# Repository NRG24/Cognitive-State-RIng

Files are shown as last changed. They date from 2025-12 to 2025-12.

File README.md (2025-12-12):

This is a sensor packed device that features a GSR sensor and max30102 sensor that measure skin electrical conductivity (arousal), temperature, spo2, heart rate, and HRV. The point of this is to build a tracker that isn't focused on fitness, but cognitive health tied to the nervous system. These sensors will be packed into a small PCB that goes on one of the two rings. There is a ring on the index finger with the PCB+ one electrode and the other ring on the middle finger has the other electrode. This data is controlled by the nrf52840, a small MCU on the PCB, and sent via Bluetooth low energy to a mobile based Flutter app. The data goes through a filter, removing any outliers. Additionally, in the app there is a "Cognitive Score." The app interprets all the data and based off of an algorithm, it can give you a score out of 100 as well as some insights.

Bill of Materials:
https://docs.google.com/spreadsheets/d/1M4TGVIU_XtcH1ejhJ6mys-NpG31-dXWfCi7Ya9xVGhs/edit?usp=sharing

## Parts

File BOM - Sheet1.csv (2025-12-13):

Item | Description | Quantity | Unit Price | Total Price | URL | FINAL TOTAL | Notes
XIAO nRF52840 Sense | Breakout MCU | 1 | $25.99 | $25.99 | https://www.amazon.com/Seeed-Studio-XIAO-nRF52840Sense/dp/B09T94SZ8K?th=1 | 27.81 | Amazon ultimately has the best price for the XIAO
Grove GSR Sensor | Breakout GSR Sensor | 1 | 10.9 | 10.9 | https://www.digikey.com/en/products/detail/seeed-technology-co-ltd/101020052/5488086 | 20.31 | REVISED: Digikey has the best price for this gsr sensor
Max30102 | Heart rate sensor breakout | 1 | 6.99 | 6.99 | https://www.amazon.com/AEDIKO-MAX30102-Detection-Concentration-Compatible/dp/B09LQDW27N | 14.96 | I can't and wont switch this. Amazon here has the best price and also there are many counterfeits of these sensors but I know this exact one works well based off research.
Aypzuke 10cm+20cm 240pc | Jumper Cables | 1 | 1.95 | 1.95 | https://www.digikey.com/en/products/detail/adafruit-industries-llc/1954/6827087?gclsrc=aw.ds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 | 9.57 | Reduced price by 10 by switching to digikey
Remote Finger Sensor For | Electrodes | 1 | 32.4 | 32.4 | https://bio-medical.com/remote-finger-sensor-for-gsr2.html | 44.9 | Best price here and it has the proper dimensions
USB_C_Receptacle_USB2.0_16P | USBC Port J1 | 2 | 0.78 | 1.56 | https://www.digikey.com/en/products/detail/gct/USB4105-GF-A-060/14559043?gclsrc=aw.ds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 | 10.73 | From here down I got the best price or only price possible
4.7uf Capacitor | Cap C6 | 2 | 0.12 | 0.24 | https://www.mouser.com/ProductDetail/TAIYO-YUDEN/LMK212BJ475KG-T | 8.93
0.1uF Capacitor | Cap C3, C_GSR1 | 4 | 0.11 | 0.44 | https://www.mouser.com/ProductDetail/581-06036C104JAT2A | 9.06
AKZYTUE 3.7V 40mAh 301020 Lipo Battery | Battery | 2 | 7.29 | 14.58 | https://www.amazon.com/AKZYTUE-Battery-Rechargeable-Lithium-Connector/dp/B07TWHGHW4?s=electronics | 23.08
MDBT50Q-P1MV2 | PCB MCU | 2 | 6 | 12 | https://www.digikey.com/en/products/detail/raytac/MDBT50Q-P1MV2/13677599?gclsrc=aw.ds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 | 34.24
KYOCERA AVX KAM15CT70J226MT | Cap c1 and c2 | 2 | 0.46 | 0.92 | https://www.mouser.com/ProductDetail/KYOCERA-AVX/KAM15CT70J226MT?qs=Tc%252BHE9vUsnt72L0VWwenIA%3D%3D | 9.63
Samsung Electro-Mechanics CL03A105MQ3CSWC | MCU CAPS | 18 | 0.065 | 1.17 | https://www.mouser.com/ProductDetail/Samsung-Electro-Mechanics/CL03A105MQ3CSWC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 | 9.99
36-5019TR-ND | Test points | 4 | 0.37 | 1.48 | https://www.digikey.com/en/products/detail/keystone-electronics/5019/3907344?gclsrc=aw.ds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 | 9.3
Draloric TNPU06034K70AZEN00 | resistors r1,r2 | 4 | 2.21 | 8.84 | https://www.mouser.com/ProductDetail/71-TNPU06034K70AZEN0 | 18.01
Panasonic ERA-3APB303V | resistor r3 | 2 | 0.24 | 0.48 | https://www.mouser.com/ProductDetail/667-ERA-3APB303V | 9.06
Bourns CR0603-FX-5101ELF | Resistor r4,r5 | 4 | 0.1 | 0.4 | https://www.mouser.com/ProductDetail/652-CR0603FX-5101ELF | 8.98
Vishay / Beyschlag MCT06030C2203FP500 | R_GSR resistor | 2 | 0.1 | 0.2 | https://www.mouser.com/ProductDetail/594-MCT06030C2203FP5 |  | Cart combined w/ item below
Panasonic ERA-3AED104V | R_PROTECT | 2 | 0.1 | 0.2 | https://www.mouser.com/ProductDetail/667-ERA-3AED104V | 8.98
579-MCP1700T1802E/TT | LDO | 2 | 0.51 | 1.02 | https://www.mouser.com/ProductDetail/Microchip-Technology/MCP1700T-1802E-TT?qs=YUl711QUJY0TiDgzmNmFrg%3D%3D | 9.64
579-MCP73831T-2ACIOT | charger | 2 | 0.76 | 1.52 | https://www.mouser.com/ProductDetail/Microchip-Technology/MCP73831T-2ACI-OT?qs=yUQqVecv4qvbBQBGbHx0Mw%3D%3D | 10.18
PCB |  | 5 |  |  |  | 50.52
 |  |  |  |  | TOTAL: | 347.88

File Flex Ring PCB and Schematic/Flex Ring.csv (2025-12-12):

Id | Designator | Footprint | Quantity | Designation | Supplier and ref
1 | C10,C12,C5,C13,C11,C9,C8,C7,C4 | C_0603_1608Metric | 9 | 1uF
2 | U4 | Nordic_AQFN-73-1EP_7x7mm_P0.5mm | 1 | nRF52840
3 | BT1 | SolderWire-0.127sqmm_1x02_P3.7mm_D0.48mm_OD1mm | 1 | Battery
4 | C1,C2 | C_0603_1608Metric | 2 | 10uF
5 | J1 | USB_C_Receptacle_HRO_TYPE-C-31-M-12 | 1 | USB_C_Receptacle_USB2.0_16P
6 | U1 | SOT-23 | 1 | MCP1700x-180xxTT
7 | U2 | SOT-23-5 | 1 | MCP73831-2-OT
8 | E1 | TestPoint_Pad_D2.0mm | 1 | TestPoint
9 | E2 | SolderWire-0.1sqmm_1x01_D0.4mm_OD1mm | 1 | TestPoint
10 | C6 | C_0805_2012Metric | 1 | 4.7uF
11 | U5 | Maxim_OLGA-14_3.3x5.6mm_P0.8mm | 1 | MAX30102
12 | R3 | R_0603_1608Metric | 1 | 30k
13 | R_PROTECT1 | R_0603_1608Metric | 1 | 100k
14 | R_GSR1 | R_0603_1608Metric | 1 | 220k
15 | C_GSR1,C3 | C_0603_1608Metric | 2 | .1uF
16 | R5,R4 | R_0603_1608Metric | 2 | 5.1k
17 | R2,R1 | R_0603_1608Metric | 2 | 4.7k
18 | J2 | PinHeader_2x05_P1.27mm_Vertical | 1 | SWD_HEADER

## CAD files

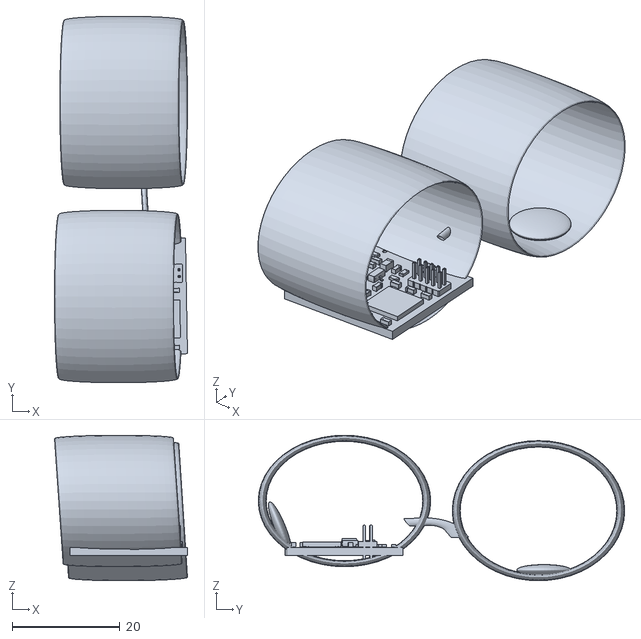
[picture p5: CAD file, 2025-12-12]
3D CAD MODEL.stl
24.7 x 68.0 x 27.0

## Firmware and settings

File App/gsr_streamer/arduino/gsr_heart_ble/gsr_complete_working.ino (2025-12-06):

#include <Wire.h>
#include "MAX30105.h"
#include "heartRate.h"
#include <ArduinoBLE.h>

MAX30105 particleSensor;

BLEService bioService("19B10000-E8F2-537E-4F6C-D104768A1214");
BLEIntCharacteristic gsrChar("19B10002-E8F2-537E-4F6C-D104768A1214", BLERead | BLENotify);
BLEIntCharacteristic heartChar("19B10003-E8F2-537E-4F6C-D104768A1214", BLERead | BLENotify);
BLEFloatCharacteristic tempChar("19B10004-E8F2-537E-4F6C-D104768A1214", BLERead | BLENotify);
BLEFloatCharacteristic hrvChar("19B10005-E8F2-537E-4F6C-D104768A1214", BLERead | BLENotify);
BLEIntCharacteristic spo2Char("19B10006-E8F2-537E-4F6C-D104768A1214", BLERead | BLENotify);

bool deviceConnected = false;

const byte RATE_SIZE = 20;
byte rates[RATE_SIZE];
byte rateSpot = 0;
long lastBeat = 0;
float beatsPerMinute = 0;
int beatAvg = 0;
float smoothedBPM = 0.0;

const int HRV_BUFFER_SIZE = 10;
unsigned long rrIntervals[HRV_BUFFER_SIZE];
int rrIndex = 0;
unsigned long lastRRTime = 0;
float hrv = 0.0;

const int GSR_PIN = A0;
float gsrValue = 0.0;
const int GSR_SAMPLES = 10;
float gsrReadings[GSR_SAMPLES] = {0};
int gsrIndex = 0;

float spo2 = 98.0;
float redACValue = 0, irACValue = 0;
float redDCValue = 0, irDCValue = 0;
int spo2SampleCount = 0;

float temperature = 0.0;
unsigned long lastTempRead = 0;
const unsigned long TEMP_READ_INTERVAL = 2000;

void setup() {
  Serial.begin(9600);
  delay(1000);
  Serial.println("=== GSR Streamer ===");
  
  Serial.print("Initializing MAX30102... ");
  if (!particleSensor.begin(Wire, I2C_SPEED_FAST)) {
    Serial.println("FAILED!");
    while (1);
  }
  Serial.println("OK");
  
  byte ledBrightness = 0x1F;
  byte sampleAverage = 4;
  byte ledMode = 2;
  int sampleRate = 400;
  int pulseWidth = 411;
  int adcRange = 4096;
  
  particleSensor.setup(ledBrightness, sampleAverage, ledMode, sampleRate, pulseWidth, adcRange);
  particleSensor.setPulseAmplitudeRed(0x1F);
  particleSensor.setPulseAmplitudeGreen(0);
  particleSensor.enableDIETEMPRDY();
  
  Serial.print("Initializing BLE... ");
  if (!BLE.begin()) {
    Serial.println("FAILED!");
    while (1);
  }
  Serial.println("OK");
  
  BLE.setLocalName("GSR_HEART");
  BLE.setAdvertisedService(bioService);
  
  bioService.addCharacteristic(gsrChar);
  bioService.addCharacteristic(heartChar);
  bioService.addCharacteristic(tempChar);
  bioService.addCharacteristic(hrvChar);
  bioService.addCharacteristic(spo2Char);
  
  BLE.addService(bioService);
  
  gsrChar.writeValue(0);
  heartChar.writeValue(0);
  tempChar.writeValue(0.0);
  hrvChar.writeValue(0.0);
  spo2Char.writeValue(0);
  
  BLE.advertise();
  Serial.println("Ready");
}

void loop() {
  BLEDevice central = BLE.central();
  
  if (central) {
    if (!deviceConnected) {
      deviceConnected = true;
      Serial.println("✓ Connected");
    }
    BLE.poll();
  } else {
    if (deviceConnected) {
      deviceConnected = false;
      Serial.println("✗ Disconnected");
    }
  }
  
  long irValue = particleSensor.getIR();
  uint32_t redValue = particleSensor.getRed();
  
  if (checkForBeat(irValue)) {
    long delta = millis() - lastBeat;
    lastBeat = millis();
    beatsPerMinute = 60 / (delta / 1000.0);
    
    if (beatsPerMinute < 255 && beatsPerMinute > 20) {
      rates[rateSpot++] = (byte)beatsPerMinute;
      rateSpot %= RATE_SIZE;
      
      beatAvg = 0;
      for (byte x = 0; x < RATE_SIZE; x++) {
        beatAvg += rates[x];
      }
      beatAvg /= RATE_SIZE;
      
      if (smoothedBPM == 0.0) {
        smoothedBPM = beatAvg;
      } else {
        smoothedBPM = (smoothedBPM * 0.85) + (beatAvg * 0.15);
      }
      
      if (lastRRTime > 0) {
        unsigned long rrInterval = millis() - lastRRTime;
        if (rrInterval > 400 && rrInterval < 1500) {
          rrIntervals[rrIndex] = rrInterval;
          rrIndex = (rrIndex + 1) % HRV_BUFFER_SIZE;
          calculateHRV();
        }
      }
      lastRRTime = millis();
    }
  }
  
  if (irValue > 50000 && redValue > 1000) {
    calculateSpO2(irValue, redValue);
  }
  
  updateGSR();
  
  if (millis() - lastTempRead >= TEMP_READ_INTERVAL) {
    temperature = particleSensor.readTemperature();
    lastTempRead = millis();
  }
  
  if (deviceConnected && central) {
    int gsrInt = constrain((int)gsrValue, 0, 1023);
    int heartInt = constrain((int)smoothedBPM, 0, 255);
    int spo2Int = constrain((int)spo2, 85, 100);
    
    gsrChar.writeValue(gsrInt);
    heartChar.writeValue(heartInt);
    tempChar.writeValue(temperature);
    hrvChar.writeValue(hrv);
    spo2Char.writeValue(spo2Int);
    
    delay(10);
  }
  
  static unsigned long lastPrint = 0;
  if (millis() - lastPrint >= 1000) {
    Serial.print("HR:");
    Serial.print((int)smoothedBPM);
    Serial.print(" GSR:");
    Serial.print((int)gsrValue);
    Serial.print(" T:");
    Serial.print(temperature, 1);
    Serial.print(" HRV:");
    Serial.print(hrv, 0);
    Serial.print(" SpO2:");
    Serial.print((int)spo2);
    
    if (deviceConnected) Serial.print(" BLE:✓");
    Serial.println();
    lastPrint = millis();
  }
}

void calculateHRV() {
  if (rrIndex < 3) return;
  
  float sumSquaredDiffs = 0;
  int validPairs = 0;
  
  for (int i = 1; i < HRV_BUFFER_SIZE; i++) {
    if (rrIntervals[i] > 0 && rrIntervals[i-1] > 0) {
      long diff = rrIntervals[i] - rrIntervals[i-1];
      sumSquaredDiffs += (diff * diff);
      validPairs++;
    }
  }
  
  if (validPairs > 1) {
    float rmssd = sqrt(sumSquaredDiffs / validPairs);
    rmssd = rmssd * 0.3;
    rmssd = constrain(rmssd, 15, 80);
    hrv = (hrv * 0.9) + (rmssd * 0.1);
  }
}

void calculateSpO2(long irValue, uint32_t redValue) {
  if (spo2SampleCount == 0) {
    redDCValue = redValue;
    irDCValue = irValue;
    spo2 = 98.0;
  }
  
  redACValue = abs(redValue - redDCValue);
  irACValue = abs(irValue - irDCValue);
  
  redDCValue = (redDCValue * 0.95) + (redValue * 0.05);
  irDCValue = (irDCValue * 0.95) + (irValue * 0.05);
  
  spo2SampleCount++;
  
  if (spo2SampleCount > 100 && irACValue > 0 && redACValue > 0) {
    float ratio = (redACValue / redDCValue) / (irACValue / irDCValue);
    
    float calculatedSpO2;
    if (ratio < 0.5) {
      calculatedSpO2 = 100;
    } else if (ratio < 1.0) {
      calculatedSpO2 = 100 - 5 * ratio;
    } else if (ratio < 2.0) {
      calculatedSpO2 = 100 - 25 * ratio;
    } else {
      calculatedSpO2 = 85;
    }
    
    calculatedSpO2 = constrain(calculatedSpO2, 85, 100);
    spo2 = (spo2 * 0.9) + (calculatedSpO2 * 0.1);
  }
}

void updateGSR() {
  float rawGSR = analogRead(GSR_PIN);
  gsrValue = rawGSR;
  
  gsrReadings[gsrIndex] = gsrValue;
  gsrIndex = (gsrIndex + 1) % GSR_SAMPLES;
  
  float sum = 0;
  for (int i = 0; i < GSR_SAMPLES; i++) {
    sum += gsrReadings[i];
  }
  gsrValue = sum / GSR_SAMPLES;
}

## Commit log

2025-12-12 Enhance README with project overview and BOM
    Added detailed project description and bill of materials.
2025-12-13 Rename 3D CAD MODEL.stl to old cad model.stl
    [old cad model.stl]
